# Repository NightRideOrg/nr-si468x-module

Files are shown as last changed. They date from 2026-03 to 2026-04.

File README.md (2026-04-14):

# 📡 Night Ride – Si468x Module

Open-source DAB/FM receiver module based on the **Silicon Labs / Skyworks Si468x series**.

This project provides hardware, software, and documentation to integrate a modern digital radio receiver into automotive and embedded Linux systems.

---

## Overview

The Si468x is a highly integrated broadcast receiver supporting:

- **DAB / DAB+**
- **FM (RDS)**
- Digital audio output via **I2S**
- Control via **SPI / I2C**

This repository focuses on building an **open and reusable platform** around the chip.

---

## Features

- Custom **M.2 E-Key module** design
- Automotive-oriented integration (infotainment systems)
- Linux driver / userspace control (WIP)
- Modular and reusable hardware design

---

## Repository Structure

```
/pcb        → KiCad schematics & PCB layouts
/driver     → Linux driver / interface code (WIP)
/tools      → debugging and testing utilities
/firmware   → placeholder (not included, see below)
```

---

## ⚠️ Firmware Notice

The Si468x requires proprietary firmware provided by the vendor.

❌ Firmware is **NOT included** in this repository  
❌ Redistribution is **not permitted**

See [`/firmware/README.md`](firmware/README.md) for details on how to obtain and use firmware.

---

## Hardware

Planned / current design goals:

- Si4689-based RF frontend
- M.2 E-Key form factor
- External antenna support
- I2S digital audio output
- SPI / I2C host interface

[View Schematic & PCB](https://maizeshark.github.io/pcbs/nr-si468x-module/)<br>
[View Schematic & PCB for the RPi adapter Hat](https://maizeshark.github.io/pcbs/nr-si468x-rpi-adapter/)

---

## Software

Planned features:

- Linux integration (userspace or kernel driver)
- Station tuning and service selection
- DAB / FM metadata parsing
- Integration into infotainment systems

---

## Documentation

Due to licensing restrictions, some vendor documentation is not included.

You may need to obtain:
- Programming guides
- Firmware files
- Additional application notes

These are typically available via:
- Community forums
- Existing development kits

---

## Status

🚧 Work in progress

- PCB: finished
- Driver: pending
- Testing: pending

---

## Licensing

This repository contains multiple components under different licenses:

- **Software (`/driver`, `/tools`)**  
  Licensed under the GNU General Public License v3.0 (GPL-3.0)

- **Hardware (`/pcb`)**  
  Licensed under the CERN Open Hardware License v2 – Strongly Reciprocal (CERN-OHL-S-2.0)

- **Firmware**  
  Not included. Proprietary and subject to vendor licensing.

See the individual folders for more details.

---

## 🌙 Night Ride

Part of the Night Ride open-source automotive platform.

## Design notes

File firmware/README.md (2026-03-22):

# Firmware

⚠️ The Si468x requires proprietary firmware which is **not included** in this repository.

## Why is firmware not included?

The firmware is:
- Proprietary
- Distributed under restrictive licenses
- Not legally redistributable

Including it in this repository would violate licensing terms.

---

## How to obtain firmware

You may be able to obtain firmware by:

- Contacting Skyworks (formerly Silicon Labs)
- Using official evaluation kits or SDKs
- Searching community forums and discussions

Example (unofficial, may change or disappear):

https://www.mikrocontroller.net/topic/342689

---

## Usage

Place firmware files in this directory:

```
firmware/
├── dab_radio_*.bin
├── fmhd_radio_*.bin
├── rom_patch*.bin
```

The software/driver will load firmware from this location.

---

## Disclaimer

This project does not provide or distribute firmware.

Users are responsible for ensuring they comply with all applicable licenses.

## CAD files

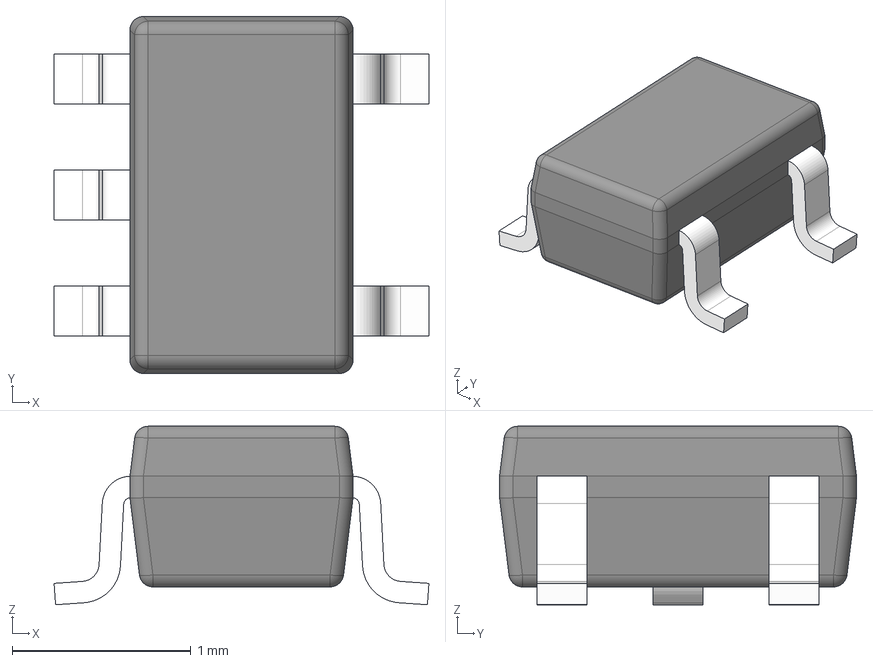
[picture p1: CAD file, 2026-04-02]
pcb/3d/DCK0005A.stp
2.10 x 2.00 x 1.00 mm
BODY-SOT
LEAD-SOT x 5
PIN1-ID

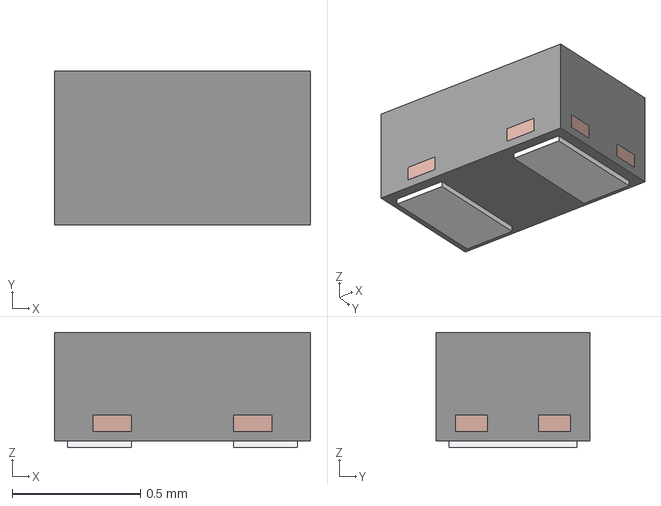
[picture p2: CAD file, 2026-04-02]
pcb/3d/DPY0002A.stp
1.00 x 0.6 x 0.45 mm
BODY-SON
FRAME-DPY0002A

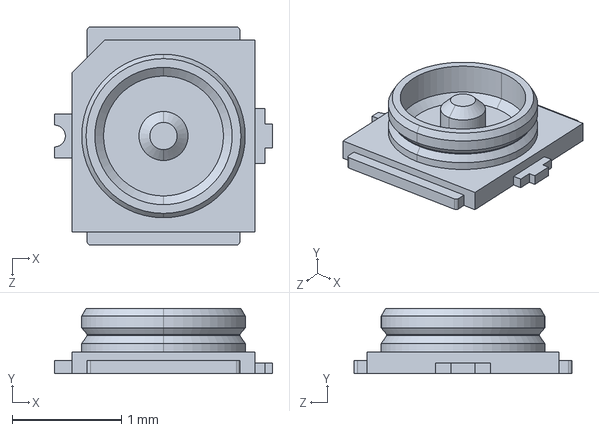
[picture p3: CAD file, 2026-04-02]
pcb/3d/20449-001E-03.step
2.00 x 0.6 x 2.00 mm

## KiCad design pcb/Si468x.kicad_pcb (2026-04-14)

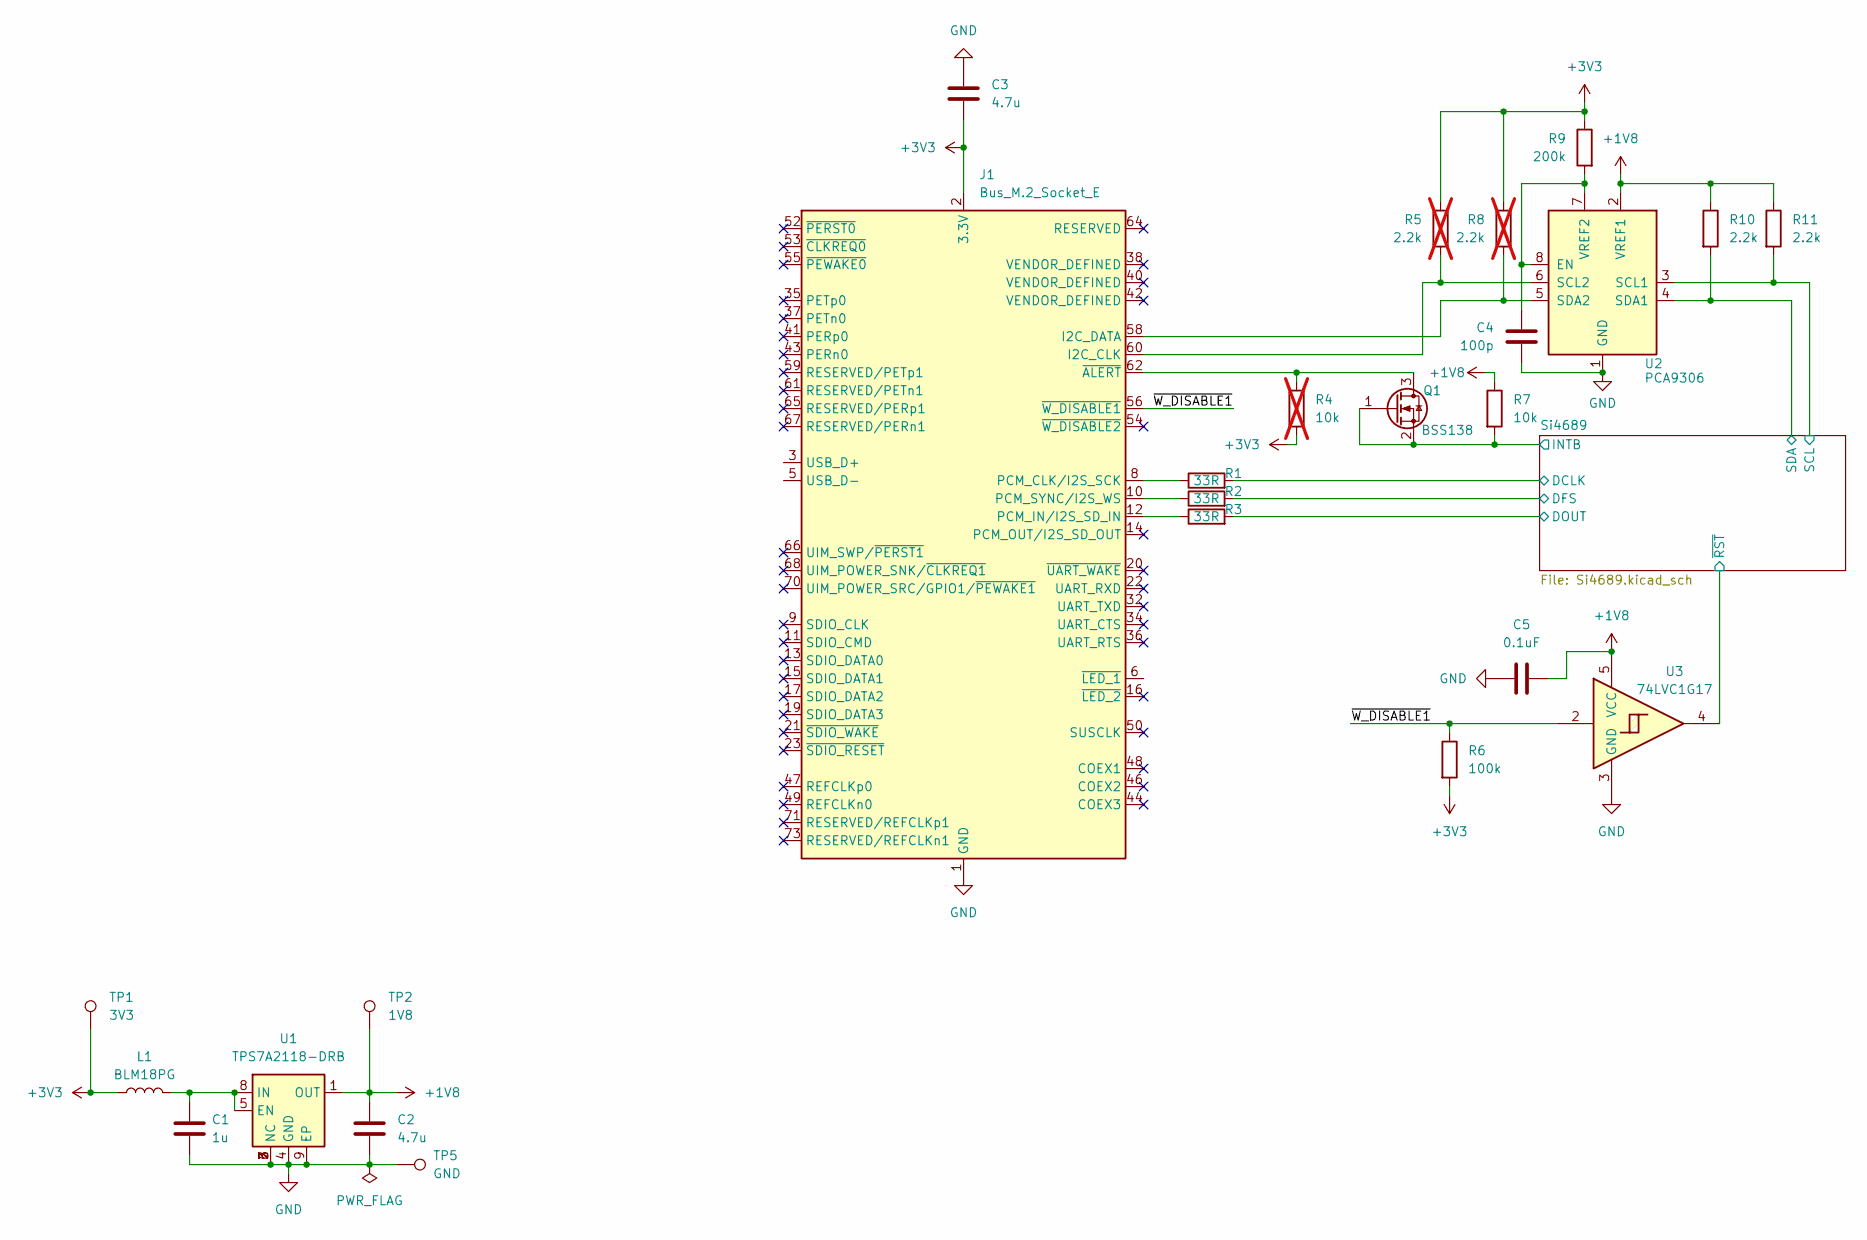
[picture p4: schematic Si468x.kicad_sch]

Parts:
C1: 1u; C_0603_1608Metric; LCSC C29936
C2, C3: 4.7u; C_0603_1608Metric; LCSC C18185770
C4: 100p; C_0402_1005Metric; LCSC C281751
C5: 0.1uF; C_0402_1005Metric; LCSC C77020
J1: Bus_M.2_Socket_E; M.2_2230-xx-E
L1: BLM18PG; L_0603_1608Metric; LCSC C80165
Q1: BSS138; SOT-23; LCSC C82045
R1, R2, R3: 33R; R_0402_1005Metric; LCSC C138002
R4: 10k; R_0402_1005Metric; LCSC C60490; not fitted
R5, R8: 2.2k; R_0402_1005Metric; LCSC C114762; not fitted
R6: 100k; R_0402_1005Metric; LCSC C60491
R7: 10k; R_0402_1005Metric; LCSC C60490
R9: 200k; R_0402_1005Metric; LCSC C60490
R10, R11: 2.2k; R_0402_1005Metric; LCSC C114762
TP1: 3V3; TestPoint_Pad_D1.0mm
TP2: 1V8; TestPoint_Pad_D1.0mm
TP5: GND; TestPoint_Pad_D1.0mm
U1: TPS7A2118-DRB; Texas_DRB_VSON_8; LCSC C35469250
U2: PCA9306; VSSOP-8_2.3x2mm_P0.5mm
U3: 74LVC1G17; Texas_R-PDSO-G5_DCK-5; LCSC C10425

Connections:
+1V8: C2.1, C5.2, R7.1, R10.1, R11.1, TP2.1, U1.1 (OUT), U2.2 (VREF1), U3.5 (VCC); also elsewhere on the board
+3V3: C3.2, J1.2 (3.3V), J1.4 (3.3V), J1.72 (3.3V), J1.74 (3.3V), L1.1, R4.2, R5.1, R6.2, R8.1, R9.1, TP1.1
/Si4689/DCLK: R1.2; also elsewhere on the board
/Si4689/DFS: R2.2; also elsewhere on the board
/Si4689/DOUT: R3.2; also elsewhere on the board
/Si4689/INTB: Q1.1 (G), Q1.2 (S), R7.2; also elsewhere on the board
/Si4689/SCL: R11.2, U2.3 (SCL1); also elsewhere on the board
/Si4689/SDA: R10.2, U2.4 (SDA1); also elsewhere on the board
/Si4689/~RST: U3.4; also elsewhere on the board
/~W_DISABLE1: J1.56 (~W_DISABLE1), R6.1, U3.2
GND: C1.2, C2.2, C3.1, C4.2, C5.1, J1.1 (GND), J1.7 (GND), J1.18 (GND), J1.33 (GND), J1.39 (GND), J1.45 (GND), J1.51 (GND), J1.57 (GND), J1.63 (GND), J1.69 (GND), J1.75 (GND), TP5.1, U1.2 (NC), U1.3 (NC), U1.4 (GND), U1.6 (NC), U1.7 (NC), U1.9 (EP), U2.1 (GND), U3.3 (GND); also elsewhere on the board
unnamed: J1.60 (I2C_CLK), R5.2, U2.6 (SCL2)
unnamed: J1.58 (I2C_DATA), R8.2, U2.5 (SDA2)
unnamed: J1.8 (PCM_CLK/I2S_SCK), R1.1
unnamed: J1.12 (PCM_IN/I2S_SD_IN), R3.1
unnamed: J1.10 (PCM_SYNC/I2S_WS), R2.1
unnamed: J1.62 (~ALERT), Q1.3 (D), R4.1
unnamed: C1.1, L1.2, U1.5 (EN), U1.8 (IN)
unnamed: C4.1, R9.2, U2.7 (VREF2), U2.8 (EN)

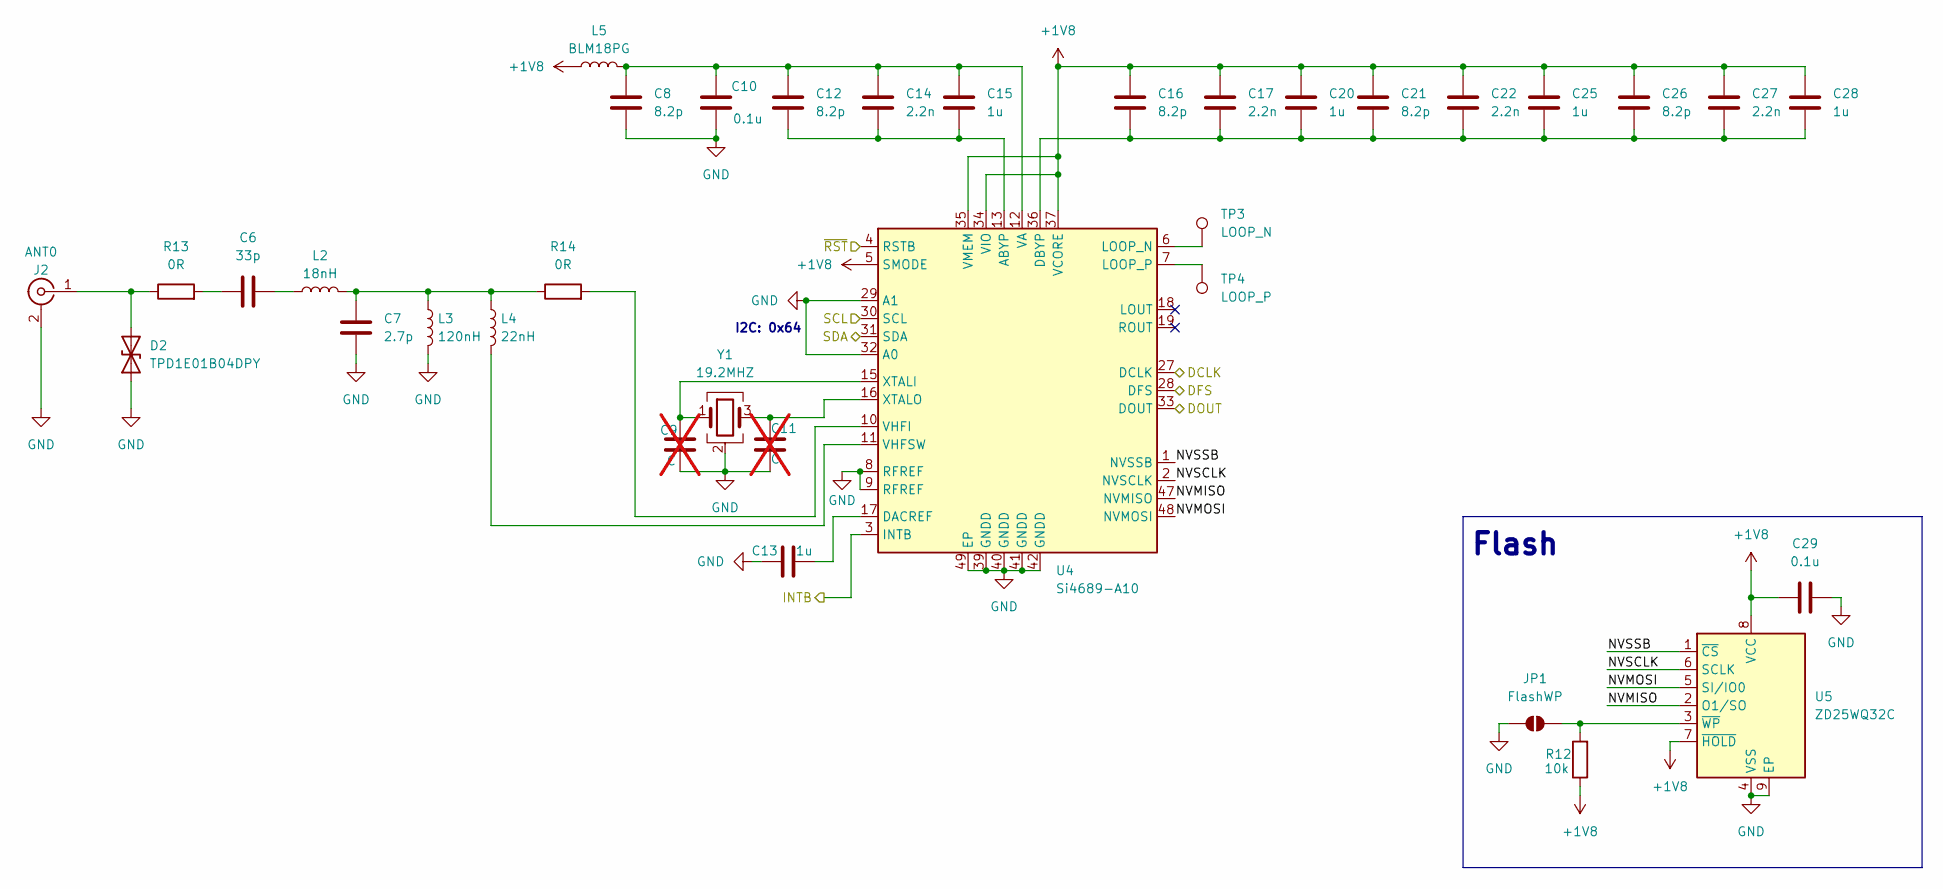
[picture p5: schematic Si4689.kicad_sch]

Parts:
C6: 33p; C_0402_1005Metric; LCSC C70465
C7: 2.7p; C_0402_1005Metric; LCSC C76904
C8, C12, C16, C21, C26: 8.2p; C_0402_1005Metric; LCSC C76984
C9, C11: C; C_0402_1005Metric; not fitted
C10, C29: 0.1u; C_0402_1005Metric; LCSC C77020
C13, C15, C20, C25, C28: 1u; C_0402_1005Metric; LCSC C576449
C14, C17, C22, C27: 2.2n; C_0402_1005Metric; LCSC C126534
D2: TPD1E01B04DPY; Texas_DPY0002A_0.6x1mm_P0.65mm; LCSC C779389
J2: ANT0; IPEX_20449-001E-03; LCSC C784401
JP1: FlashWP; SolderJumper-2_P1.3mm_Open_RoundedPad1.0x1.5mm
L2: 18nH; L_0402_1005Metric; LCSC C668381
L3: 120nH; L_0402_1005Metric; LCSC C113123
L4: 22nH; L_0402_1005Metric; LCSC C703122
L5: BLM18PG; L_0603_1608Metric; LCSC C80165
R12: 10k; R_0402_1005Metric; LCSC C60490
R13, R14: 0R; R_0402_1005Metric; LCSC C106231
TP3: LOOP_N; TestPoint_Pad_D1.0mm
TP4: LOOP_P; TestPoint_Pad_D1.0mm
U4: Si4689-A10; QFN-48_EP_7x7_Pitch0.5mm; LCSC C1526087
U5: ZD25WQ32C; Winbond_USON-8-1EP_3x2mm_P0.5mm_EP0.2x1.6mm; LCSC C5258281
Y1: 19.2MHZ; Crystal_SMD_3225-4Pin_3.2x2.5mm; LCSC C1986852

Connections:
+1V8: C16.1, C17.1, C20.1, C21.1, C22.1, C25.1, C26.1, C27.1, C28.1, C29.1, L5.1, R12.1, U4.5 (SMODE), U4.34 (VIO), U4.35 (VMEM), U4.37 (VCORE), U5.7 (~HOLD), U5.8 (VCC); also elsewhere on the board
/Si4689/DCLK: U4.27 (DCLK); also elsewhere on the board
/Si4689/DFS: U4.28 (DFS); also elsewhere on the board
/Si4689/DOUT: U4.33 (DOUT); also elsewhere on the board
/Si4689/INTB: U4.3 (INTB); also elsewhere on the board
/Si4689/NVMISO: U4.47 (NVMISO), U5.2 (O1/SO)
/Si4689/NVMOSI: U4.48 (NVMOSI), U5.5 (SI/IO0)
/Si4689/NVSCLK: U4.2 (NVSCLK), U5.6 (SCLK)
/Si4689/NVSSB: U4.1 (NVSSB), U5.1 (~CS)
/Si4689/SCL: U4.30 (SCL); also elsewhere on the board
/Si4689/SDA: U4.31 (SDA); also elsewhere on the board
/Si4689/~RST: U4.4 (RSTB); also elsewhere on the board
GND: C7.2, C8.2, C9.2, C10.2, C11.2, C13.1, C29.2, D2.1 (A1), J2.2 (Ext), JP1.1 (A), L3.2, U4.8 (RFREF), U4.9 (RFREF), U4.29 (A1), U4.32 (A0), U4.39 (GNDD), U4.40 (GNDD), U4.41 (GNDD), U4.42 (GNDD), U4.49 (EP), U5.4 (VSS), U5.9 (EP), Y1.2 (G), Y1.4 (G); also elsewhere on the board
unnamed: C6.1, R13.2
unnamed: C6.2, L2.1
unnamed: C7.1, L2.2, L3.1, L4.1, R14.1
unnamed: D2.2 (A2), J2.1 (In), R13.1
unnamed: JP1.2 (B), R12.2, U5.3 (~WP)
unnamed: C12.2, C14.2, C15.2, U4.13 (ABYP)
unnamed: C13.2, U4.17 (DACREF)
unnamed: C16.2, C17.2, C20.2, C21.2, C22.2, C25.2, C26.2, C27.2, C28.2, U4.36 (DBYP)
unnamed: TP3.1, U4.6 (LOOP_N)
unnamed: TP4.1, U4.7 (LOOP_P)
unnamed: C8.1, C10.1, C12.1, C14.1, C15.1, L5.2, U4.12 (VA)
unnamed: R14.2, U4.10 (VHFI)
unnamed: L4.2, U4.11 (VHFSW)
unnamed: C9.1, U4.15 (XTALI), Y1.1
unnamed: C11.1, U4.16 (XTALO), Y1.3

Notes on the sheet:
I2C: 0x64
Flash

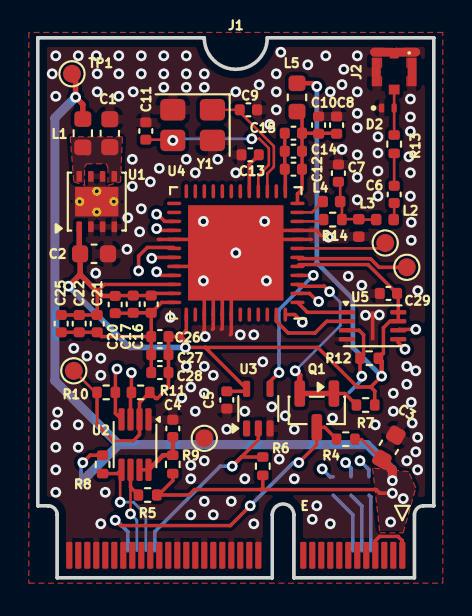
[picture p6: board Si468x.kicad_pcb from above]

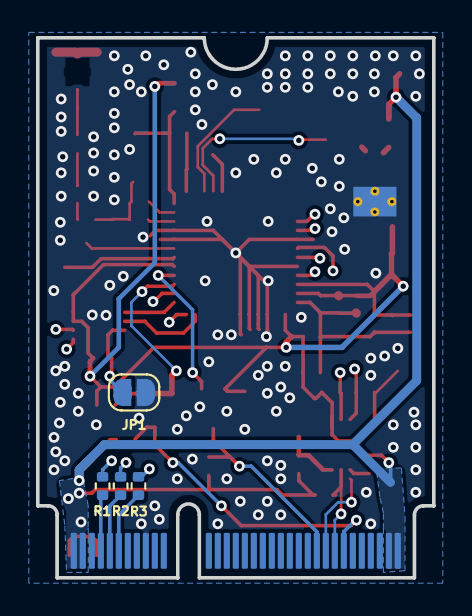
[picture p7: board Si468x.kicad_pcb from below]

Board: 4 copper layers, 22.0 x 30.0 mm, 60 parts (4 on the bottom side), 38 nets.

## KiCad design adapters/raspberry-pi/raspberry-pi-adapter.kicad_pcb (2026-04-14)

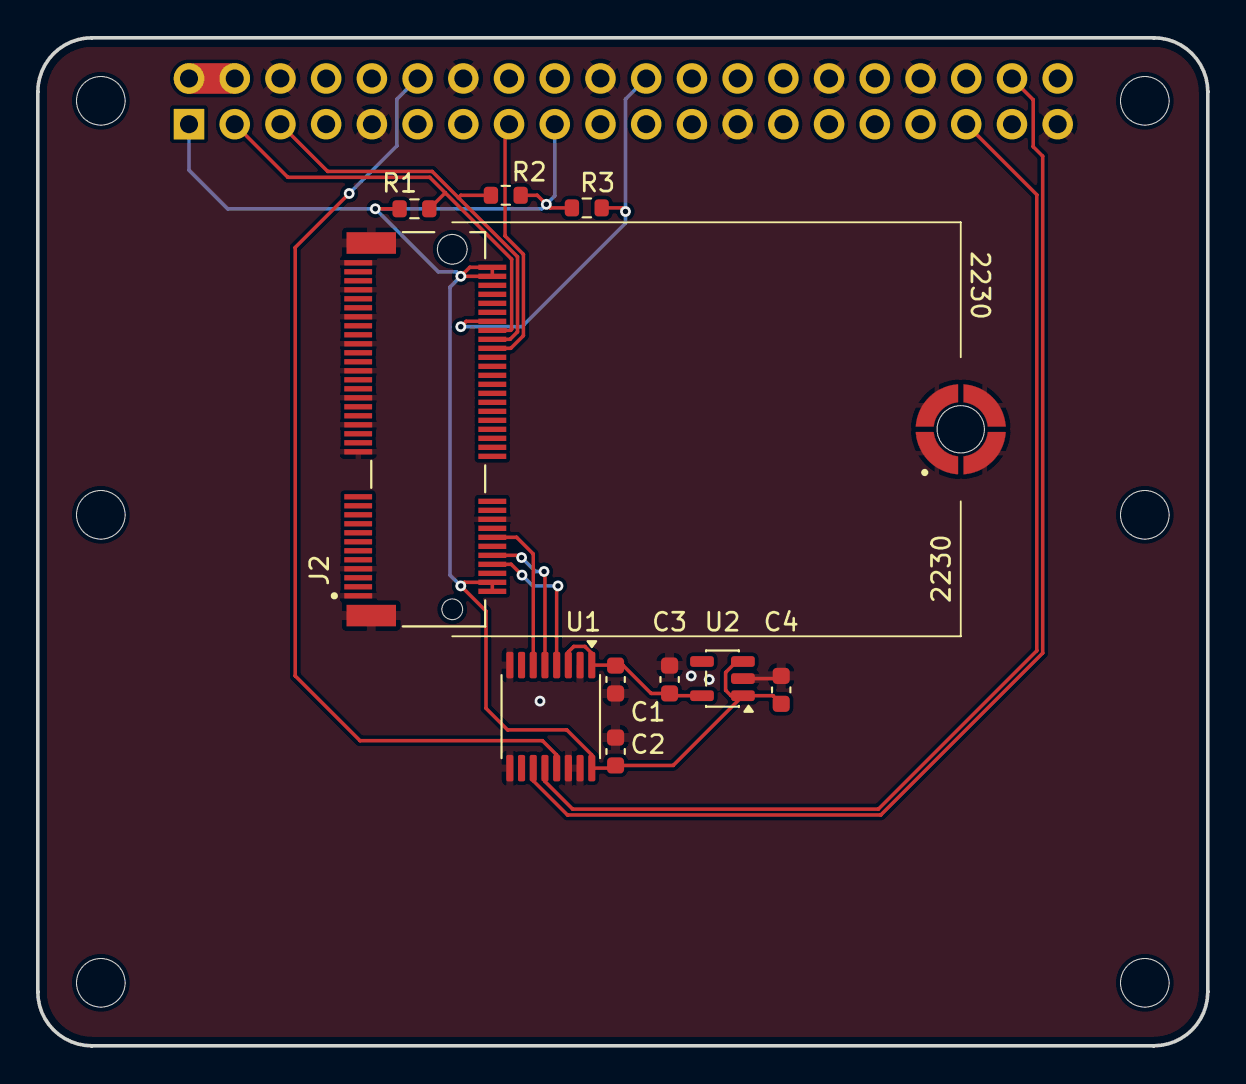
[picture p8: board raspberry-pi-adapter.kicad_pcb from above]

Board: 2 copper layers, 65.0 x 56.0 mm, 17 parts (1 on the bottom side), 14 nets.

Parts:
C1, C2: 0.1uF; C_0603_1608Metric
C3, C4: 1uF; C_0603_1608Metric
H1, H2, H3, H4, H5, H6: MountingHole; MountingHole_2.7mm_M2.5
J2: Bus_M.2_Socket_E; JAE_SM3ZS067U310AER1200
J3: Raspberry_Pi_4; PinSocket_2x20_P2.54mm_Vertical
R1, R2, R3: 10k; R_0603_1608Metric
U1: SN74AXC4T245PW; TSSOP-16_4.4x5mm_P0.65mm
U2: TLV70018_SOT23-5; SOT-23-5

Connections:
+1V8: C1.1, C3.1, U1.1 (VCCA), U1.3 (2DIR), U2.5 (OUT)
+3V3: C2.2, C4.1, J2.2 (3.3V), J2.4 (3.3V), J2.72 (3.3V), J2.74 (3.3V), J3.1 (3V3), J3.17 (3V3), R1.1, R2.1, R3.1, U1.16 (VCCB), U2.1 (IN), U2.3 (EN)
+5V: J3.2 (5V), J3.4 (5V)
/PCM_CLK: J3.12 (GPIO18/SPI1_~CE0/PCM_CLK/PWM0), U1.13 (1B1)
/PCM_CLK_1V8: J2.8 (PCM_CLK/I2S_SCK), U1.4 (1A1)
/PCM_DIN: J3.38 (GPIO20/SPI1_MOSI/PCM_DIN/PWM1), U1.11 (2B1)
/PCM_DOUT_1V8: J2.14 (PCM_OUT/I2S_SD_OUT), U1.6 (2A1)
/PCM_FS: J3.35 (GPIO19/SPI1_MISO/PCM_FS), U1.12 (1B2)
/PCM_FS_1V8: J2.10 (PCM_SYNC/I2S_WS), U1.5 (1A2)
/SCL: J2.58 (I2C_DATA), J3.5 (SCL_I2C1/GPIO03), R2.2
/SDA: J2.60 (I2C_CLK), J3.3 (SDA_I2C1/GPIO02), R1.2
/~ALERT: J2.62 (~ALERT), J3.22 (GPIO25/SDIO_DAT1), R3.2
/~W_DISABLE1: J2.56 (~W_DISABLE1), J3.15 (GPIO22/SDIO_CLK)
GND: C1.2, C2.1, C3.2, C4.2, J2.1 (GND), J2.7 (GND), J2.18 (GND), J2.33 (GND), J2.39 (GND), J2.45 (GND), J2.51 (GND), J2.57 (GND), J2.63 (GND), J2.69 (GND), J2.75 (GND), J2.M1, J2.S1 (MP), J2.S2 (MP), J3.6 (GND), J3.9 (GND), J3.14 (GND), J3.20 (GND), J3.25 (GND), J3.30 (GND), J3.34 (GND), J3.39 (GND), U1.2 (1DIR), U1.8 (GND), U1.9 (GND), U1.14 (2~OE), U1.15 (1~OE), U2.2 (GND)

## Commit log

2026-04-02 main PCB basicly finished
    [20449-001E-03.step, DCK0005A.stp, DPY0002A.stp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]
2026-04-14 bought like that
    [Si468x.kicad_pcb, Si468x.kicad_sch, raspberry-pi-adapter.kicad_pcb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]
2026-04-14 Revise PCB status and add schematic & PCBs links
    Updated PCB status to finished and added links to schematics & PCBs.
